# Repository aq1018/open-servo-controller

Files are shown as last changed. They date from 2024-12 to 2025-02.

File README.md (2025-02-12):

# open-servo-controller

An smart open servo controller board and firmware for common servos such as SG90 / MG90.

## Goals

Currently this project is under development. I'm working on this in my spare time and there is no guarantee that any of the goals will be achieved at all.

* More sophisticated control scheme via cascaded control loops instead of simple PID.
* Allow Position / Torque / Current feedback.
* I2C & UART communication.
* Clear and easy instructions to modify existing servos.
* Arduino plugin to control servo via I2C / UART.

## Status

* **Servo Dev Board** (`hardware/servo-dev-board`) - This is the board first developed to facility the development of the firmware. Currently, all major components except I2C & UART has been tested to be working correctly.
* **Firmware** (`firmware/open-servo-controller`) - The firmware is written in Rust. This is currently under active development.

All other folders are not ready yet.

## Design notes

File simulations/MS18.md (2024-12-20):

# Miuzei Micro Servo 9g MS18 ( SG90 Clone )

This is a tower-pro SG90 Clone.

## Motor Constants

### Motor Resistance - *R*

**5Ω**

This is measured by supplying 5V of power from a power bench, hold down the motor to prevent it from spinning to induce stalling, and recording the current draw. On average, the stall current at 5V is 1A.

### RPM

**6,000 RPM @ 5V**

This measured by matching the motor noise pitch against a reference pure sign wave pitch. It is determined to be at 600Hz at 5V. Since the motor has 3 winds / poles, and 2 brushes, it will make a sound 6 times per revolution. This gives us 600Hz/6 = 100Hz. Or 6,000 RPM.

### No Load Current - i<sub>o</sub>

**135mA**

This measured by supplying a 5V power and let the motor spin freely. The resulting current measurement is averaged.

### Motor Speed Constant - K<sub>v</sub>

Formula: Kv = RPM/(v − i<sub>o</sub>R) = (6,000 * PI / 30) / (5 - 0.135 * 5) = **145.276 Rad/s/V**

### Motor Torque Constant - K<sub>t</sub>

Formula: 1/Kv ( in standard metrics ) = 6.883 * 10^-3 N*m/A

### Motor Constant - K<sub>m</sub>

Formula: K<sub>m</sub> = K<sub>t</sub>/sqrt(R) = 3.078 * 10^-3 N*m/sqrt(W)

### Stall Current

Formula: I = V/R = 5/5 = 1A

## Stall Torque

Formula: T<sub>s</sub> = I<sub>s</sub> * K<sub>t</sub> = 6.883 * 10^-3 N*m

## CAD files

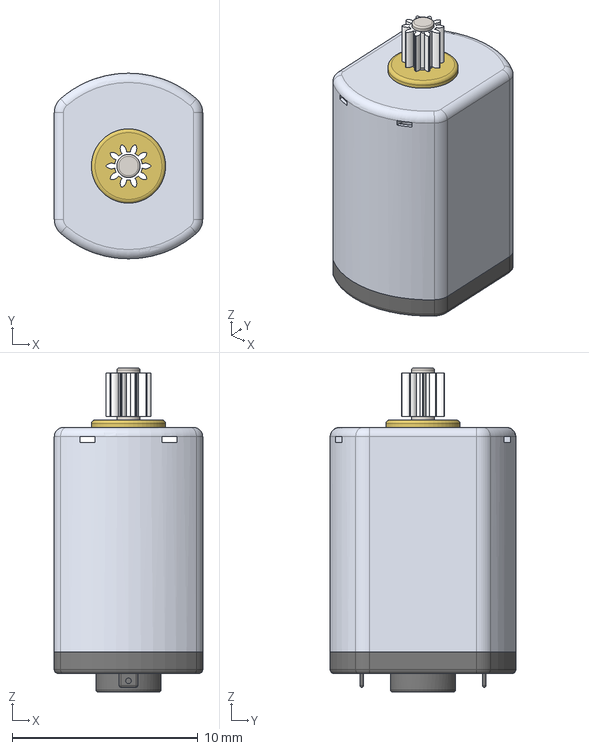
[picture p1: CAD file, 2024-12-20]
hardware/common/3DModels/sg90_motor.stp
8.00 x 10.0 x 17.4 mm
microBrushedMotor x 4
Gear5

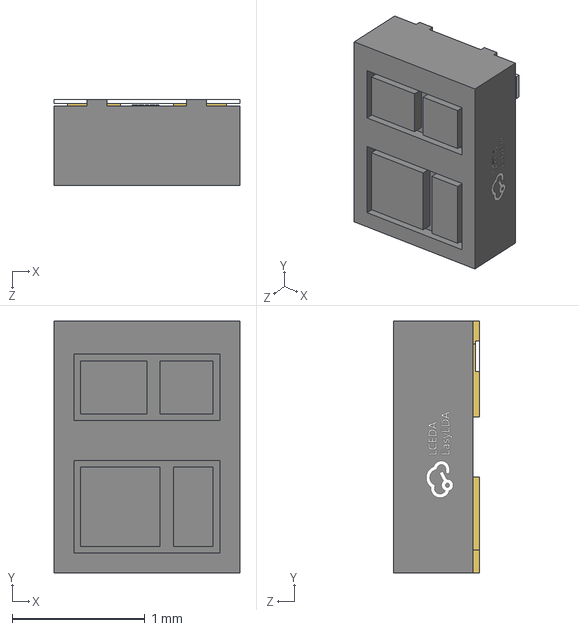
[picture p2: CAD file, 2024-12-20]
hardware/common/3DModels/OPTO-SMD-4_ITR1204SR10A.step
1.40 x 1.90 x 0.651 mm

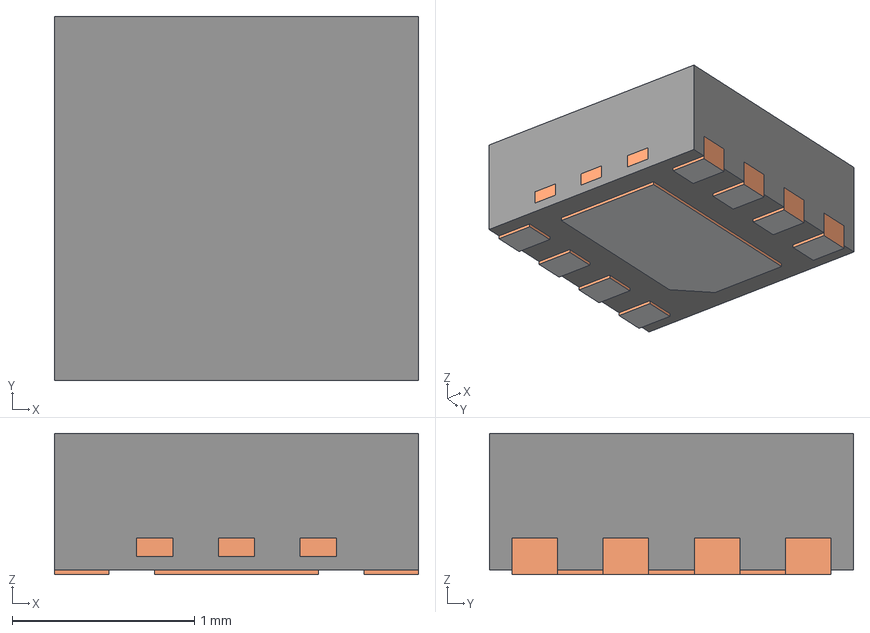
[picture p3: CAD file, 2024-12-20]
hardware/common/3DModels/DSG0008A.stp
2.00 x 2.00 x 0.775 mm
BODY-SON
FRAME-DSG0008A
PIN1-ID

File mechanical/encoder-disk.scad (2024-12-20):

include <./lib/gears.scad>

difference() {
    $fn = 128;
    cylinder(3, 10, 10);

    translate([0,0,0.5]) {
        spur_gear(0.23, 10, 3, 0);
    }
}

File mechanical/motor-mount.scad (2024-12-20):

module arc(start, end, angle, dir = "cw") {
  // find the distance of start and end vectors.
  x = end.x - start.x; // 3
  y = end.y - start.y; // 4
  d = sqrt(x * x + y * y); // 5
  rotation = atan2(y, x);

  opposite = d / 2;
  hypotenuse = opposite / sin(angle / 2);
  adjacent = cos(angle / 2) * hypotenuse;

  echo(hypotenuse, opposite, adjacent, rotation);

  translate([x/2 + start.x, y/2 + start.y, 0])
  rotate(dir == "cw" ? rotation : -rotation, [0, 0, 1])
  translate([0, - adjacent, 0])
  difference() {
    circle(hypotenuse, $fn=100);
    translate([0, adjacent - hypotenuse, 0]) 
      square(hypotenuse*2, true);
  }


    // translate([-opposite*sin(rotation), -opposite*cos(rotation), 0])
    // rotate(-rotation, [0, 0, 1])
    //   square(hypotenuse*2, true);
}

module outline(r, delta, chamfer) {
  difference() {
    offset(r=r, delta=delta, chamfer=chamfer) children();
    children();
  }
}

module motor_mount(length=6, width=8, diameter=10, thickness=2) {

    // intersection() {
      square([length, width], true);
      circle(d=diameter);
    // }

}

motor_mount();

// arc([3, 2], [3, -2], 80);

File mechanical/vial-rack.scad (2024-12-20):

function offset(edge_spacing, spacing, hole_diameter, col, row) = [
  edge_spacing.x + hole_diameter / 2 + (hole_diameter + spacing.x) * col,
  edge_spacing.y + hole_diameter / 2 + (hole_diameter + spacing.y) * row,
];

module vial_rack_leg(leg_size, leg_thickness) {
  difference() {
    cube([leg_size.x, leg_size.y, leg_size.z]);
    translate([leg_thickness, leg_thickness, -1]) cube([leg_size.x - leg_thickness + 1, leg_size.y - leg_thickness + 1, leg_size.z + 2]);
  }
}

module vial_rack(
  hole_diameter = 15,
  thickness = 8,
  grid = [10, 5],
  spacing = [10, 10],
  edge_spacing = [15, 15],
  leg_size = [15, 15, 35],
  leg_thickness = 5,
) {
  length = (hole_diameter + spacing.x) * grid.x - spacing.x + edge_spacing.x * 2;
  width = (hole_diameter + spacing.y) * grid.y - spacing.y + edge_spacing.y * 2;

  translate([-length/2, -width/2]) {
    union() {
      // rack top
      difference() {
        cube([length, width, thickness]);

        union() {
          for (x = [0:grid.x - 1]) {
            for (y = [0:grid.y - 1]) {
              pos = offset(edge_spacing, spacing, hole_diameter, x, y);
              translate([pos.x, pos.y, -1]) {
                cylinder(h=thickness + 2, d=hole_diameter);
              }
            }
          }
        }
      }

      // rack leg lower left
      translate([0, 0, thickness]) {
        rotate(0) {
          vial_rack_leg(leg_size, leg_thickness);
        }
      }

      // rack leg lower right
      translate([length, 0, thickness]) {
        rotate(90) {
          vial_rack_leg(leg_size, leg_thickness);
        }
      }

      // rack leg upper right
      translate([length, width, thickness]) {
        rotate(180) {
          vial_rack_leg(leg_size, leg_thickness);
        }
      }

      // rack leg upper left
      translate([0, width, thickness]) {
        rotate(270) {
          vial_rack_leg(leg_size, leg_thickness);
        }
      }
    }
  }
}

vial_rack();

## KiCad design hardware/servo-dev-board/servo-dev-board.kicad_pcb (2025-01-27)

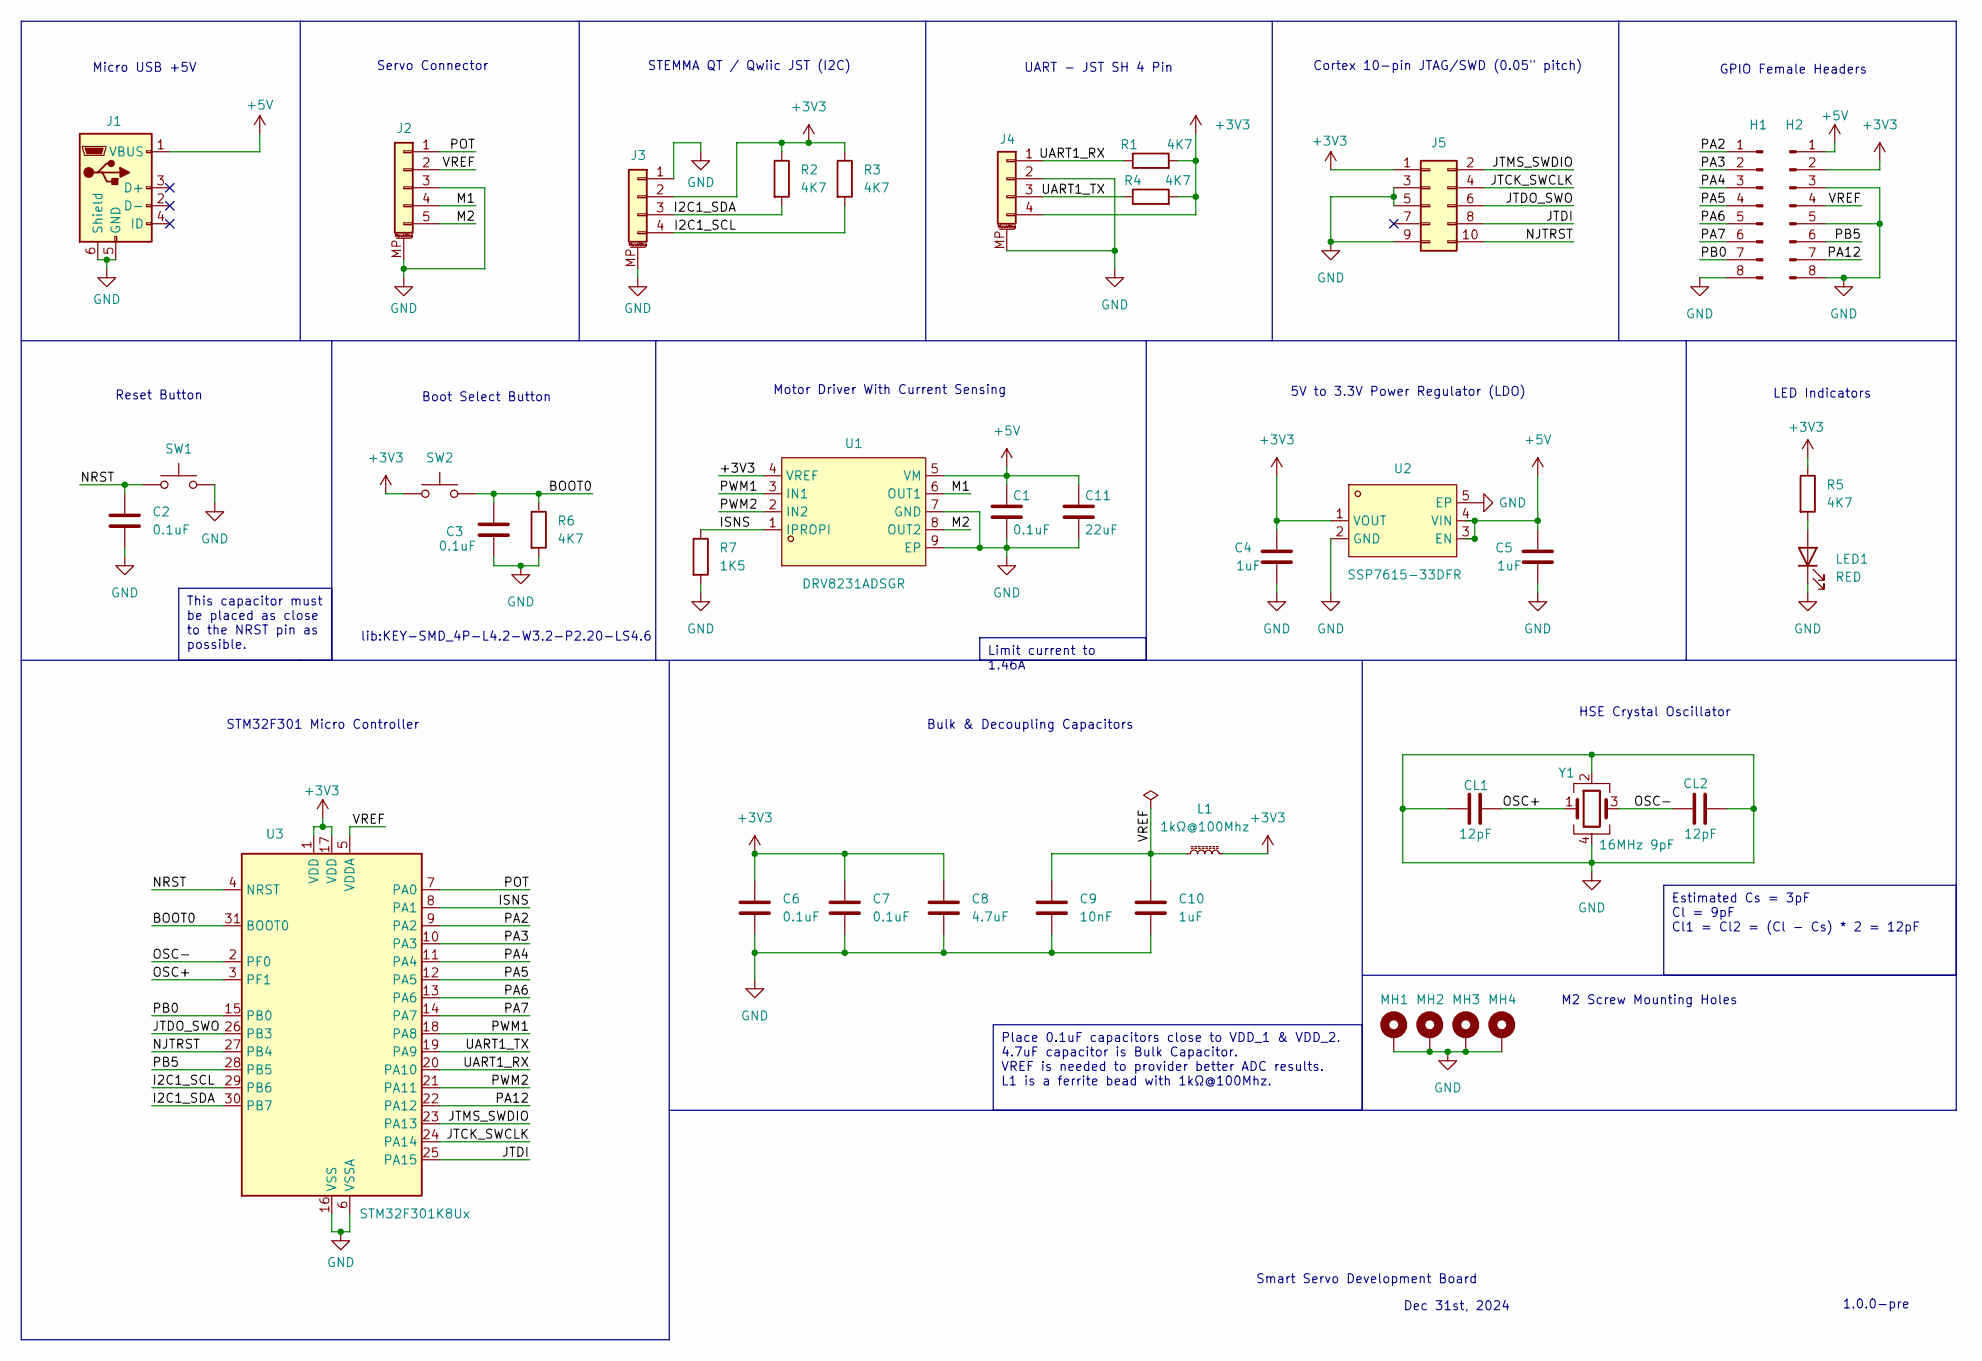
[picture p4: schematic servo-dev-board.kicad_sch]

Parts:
C1, C2, C3, C6, C7: 0.1uF; C_0402_1005Metric; LCSC C1525
C4, C5, C10: 1uF; C_0402_1005Metric; LCSC C52923
C8: 4.7uF; C_0603_1608Metric; LCSC C19666
C9: 10nF; C_0402_1005Metric; LCSC C15195
C11: 22uF; C_0603_1608Metric; LCSC C59461
CL1, CL2: 12pF; C_0402_1005Metric; LCSC C1547
H1, H2: Conn_01x08_Pin; PinHeader_1x08_P2.54mm_Vertical; LCSC C6332201
J1: USB_B_Micro; USB_Micro-B_Amphenol_10103594-0001LF_Horizontal; LCSC C428495
J2: Conn_01x05_MountingPin; JST_ZH_B5B-ZR-SM4-TF_1x05-1MP_P1.50mm_Vertical; LCSC C265440
J3, J4: Conn_01x04_MountingPin; JST_SH_BM04B-SRSS-TB_1x04-1MP_P1.00mm_Vertical; LCSC C160390
J5: Conn_02x05_Odd_Even; IDC-TH_10P-P1.27-X1270WV-2X05A-6TV01; LCSC C2962225
L1: 1kΩ@100Mhz; L_0402_1005Metric; LCSC C76883
LED1: RED; LED_0603_1608Metric; LCSC C2286
MH1, MH2, MH3, MH4: MountingHole_Pad_MP; MountingHole_2.2mm_M2_Pad_Via
R1, R2, R3, R4, R5, R6: 4K7; R_0402_1005Metric; LCSC C25792
R7: 1K5; R_0402_1005Metric; LCSC C25867
SW1, SW2: SW_Push; SW_SPST_PTS810; LCSC C221895
U1: DRV8231ADSGR; WSON-8-1EP_2x2mm_P0.5mm_EP0.9x1.6mm; LCSC Part C5139865
U2: SSP7615-33DFR; UDFN-4-1EP_1x1mm_P0.65mm_EP0.48x0.48mm; LCSC Part C3011523
U3: STM32F301K8Ux; QFN-32-1EP_5x5mm_P0.5mm_EP3.45x3.45mm; LCSC C111684
Y1: 16MHz 9pF; Crystal_SMD_3225-4Pin_3.2x2.5mm; LCSC C13738

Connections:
+3V3: C4.2, C6.2, C7.2, C8.2, H2.2, J3.2, J4.4, J5.1, L1.2, R1.2, R2.1, R3.1, R4.2, R5.1, SW2.1, U1.4 (VREF), U2.1 (VOUT), U3.1 (VDD), U3.17 (VDD)
+5V: C1.2, C5.2, C11.2, H2.1, J1.1 (VBUS), U1.5 (VM), U2.3 (EN), U2.4 (VIN)
/BOOT0: C3.1, R6.1, SW2.2, U3.31 (BOOT0)
/I2C1_SCL: J3.4, R3.2, U3.29 (PB6)
/I2C1_SDA: J3.3, R2.2, U3.30 (PB7)
/ISNS: R7.1, U1.1 (IPROPI), U3.8 (PA1)
/JTCK_SWCLK: J5.4, U3.24 (PA14)
/JTDI: J5.8, U3.25 (PA15)
/JTDO_SWO: J5.6, U3.26 (PB3)
/JTMS_SWDIO: J5.2, U3.23 (PA13)
/M1: J2.4, U1.6 (OUT1)
/M2: J2.5, U1.8 (OUT2)
/NJTRST: J5.10, U3.27 (PB4)
/NRST: C2.2, SW1.1, U3.4 (NRST)
/OSC+: CL1.1, U3.3 (PF1), Y1.1
/OSC-: CL2.2, U3.2 (PF0), Y1.3
/PA2: H1.1, U3.9 (PA2)
/PA3: H1.2, U3.10 (PA3)
/PA4: H1.3, U3.11 (PA4)
/PA5: H1.4, U3.12 (PA5)
/PA6: H1.5, U3.13 (PA6)
/PA7: H1.6, U3.14 (PA7)
/PA12: H2.7, U3.22 (PA12)
/PB0: H1.7, U3.15 (PB0)
/PB5: H2.6, U3.28 (PB5)
/POT: J2.1, U3.7 (PA0)
/PWM1: U1.3 (IN1), U3.18 (PA8)
/PWM2: U1.2 (IN2), U3.21 (PA11)
/UART1_RX: J4.1, R1.1, U3.20 (PA10)
/UART1_TX: J4.3, R4.1, U3.19 (PA9)
/VREF: C9.2, C10.2, H2.4, J2.2, L1.1, U3.5 (VDDA)
GND: C1.1, C2.1, C3.2, C4.1, C5.1, C6.1, C7.1, C8.1, C9.1, C10.1, C11.1, CL1.2, CL2.1, H1.8, H2.3, H2.5, H2.8, J1.5 (GND), J1.6 (Shield), J2.3, J2.MP (MountPin), J3.1, J3.MP (MountPin), J4.2, J4.MP (MountPin), J5.3, J5.5, J5.9, LED1.1 (K), MH1.1 (MP), MH2.1 (MP), MH3.1 (MP), MH4.1 (MP), R6.2, R7.2, SW1.2, U1.7 (GND), U1.9 (EP), U2.2 (GND), U2.5 (EP), U3.6 (VSSA), U3.16 (VSS), U3.32 (VSS), U3.33 (VSS), Y1.2, Y1.4
unnamed: LED1.2 (A), R5.2

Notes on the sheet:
This capacitor must be placed as close to the NRST pin as possible.
Place 0.1uF capacitors close to VDD_1 & VDD_2. 4.7uF capacitor is Bulk Capacitor. VREF is needed to provider better ADC results. L1 is a ferrite bead with 1kΩ@100Mhz.
Limit current to 1.46A
Estimated Cs = 3pF Cl = 9pF Cl1 = Cl2 = (Cl - Cs) * 2 = 12pF
Cortex 10-pin JTAG/SWD (0.05" pitch)
Dec 31st, 2024
Reset Button
Smart Servo Development Board
STM32F301 Micro Controller
Boot Select Button
Servo Connector
Bulk & Decoupling Capacitors
GPIO Female Headers
1.0.0-pre
5V to 3.3V Power Regulator (LDO)
LED Indicators
Micro USB +5V
M2 Screw Mounting Holes
UART - JST SH 4 Pin
STEMMA QT / Qwiic JST (I2C)
HSE Crystal Oscillator
lib:KEY-SMD_4P-L4.2-W3.2-P2.20-LS4.6
Motor Driver With Current Sensing

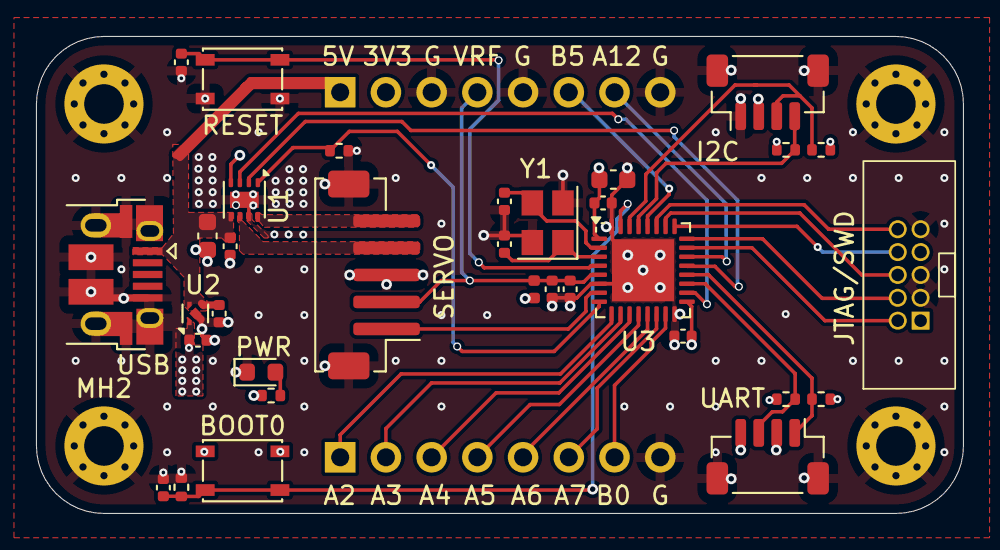
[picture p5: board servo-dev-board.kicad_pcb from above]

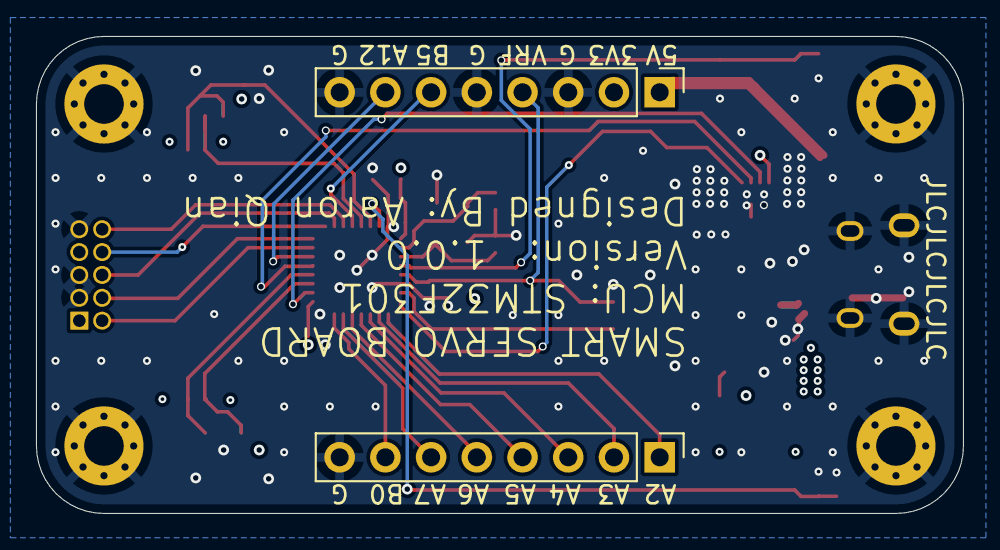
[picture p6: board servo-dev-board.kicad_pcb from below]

Board: 4 copper layers, 51.5 x 26.5 mm, 39 parts (2 on the bottom side), 33 nets.

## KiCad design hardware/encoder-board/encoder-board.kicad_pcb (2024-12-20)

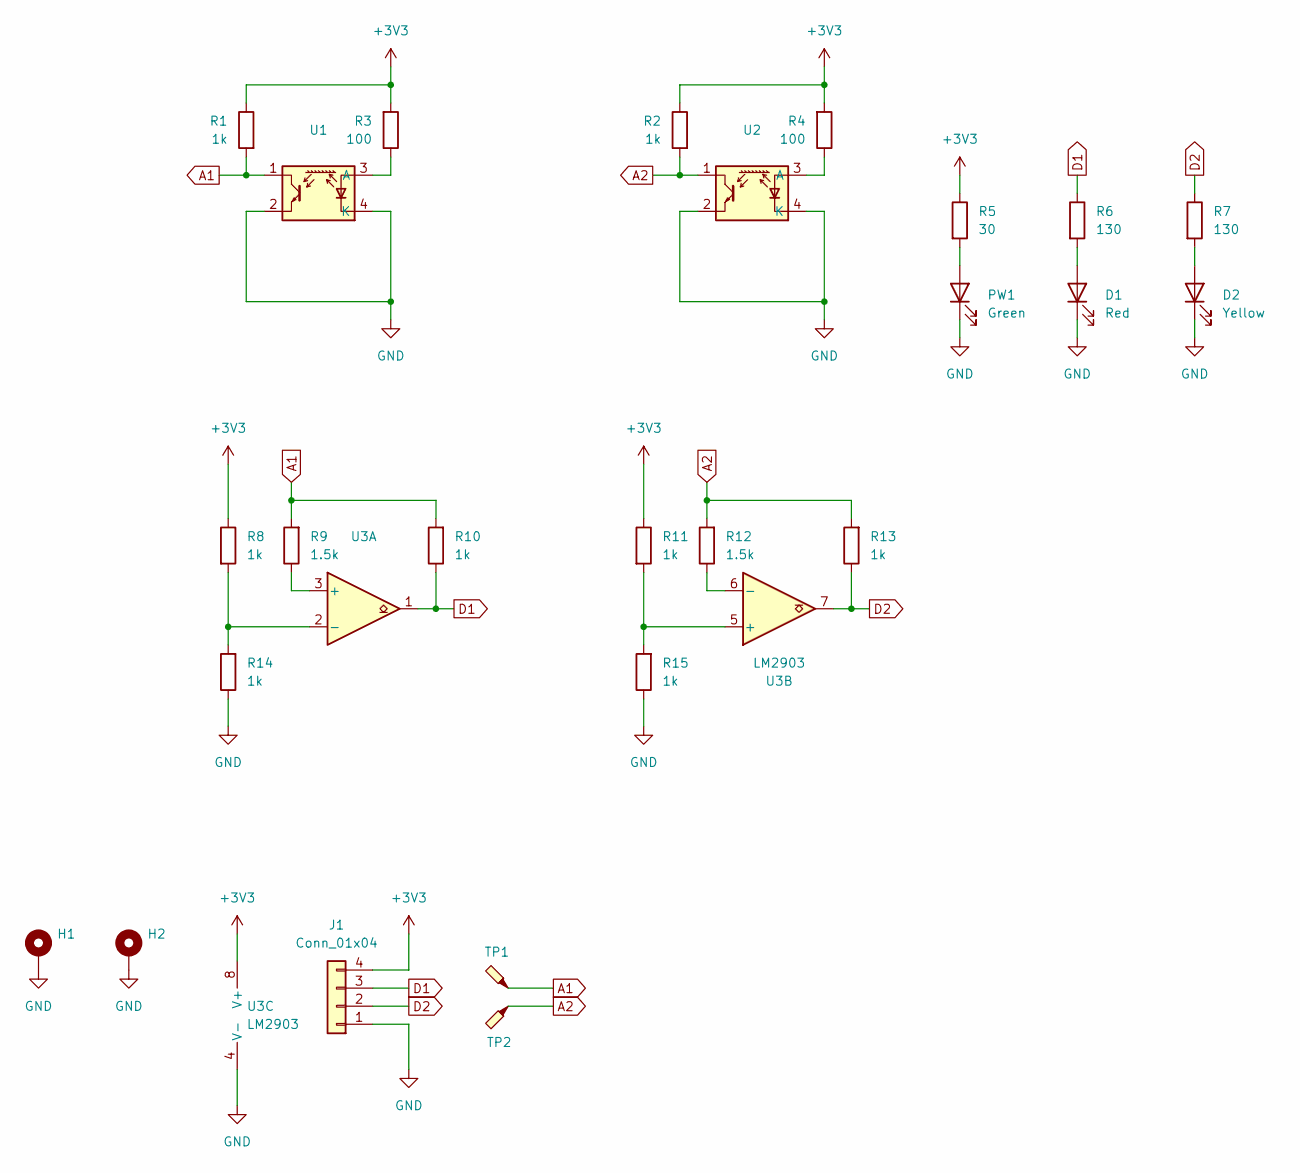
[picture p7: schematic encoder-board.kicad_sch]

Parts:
D1: Red; LED_0603_1608Metric; LCSC C497918
D2: Yellow; LED_0603_1608Metric; LCSC C497929
H1, H2: MountingHole_Pad; MountingHole_2.2mm_M2_ISO7380_Pad
J1: Conn_01x04; PinHeader_1x04_P2.54mm_Vertical_SMD_Pin1Right; LCSC C780062
PW1: Green; LED_0603_1608Metric; LCSC C497927
R1, R2, R8, R10, R11, R13, R14, R15: 1k; R_0603_1608Metric; LCSC C22548
R3, R4: 100; R_0603_1608Metric; LCSC C125923
R5: 30; R_0603_1608Metric; LCSC C128060
R6, R7: 130; R_0603_1608Metric; LCSC C2933138
R9, R12: 1.5k; R_0603_1608Metric; LCSC C114668
TP1, TP2: TestPoint_Pad_D1.0mm
U1, U2: ITR1204SR10A_TR(BY); OPTO-SMD-4_ITR1204SR10A; LCSC C475373
U3: LM2903; SOIC-8_3.9x4.9mm_P1.27mm; LCSC C98194

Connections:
+3V3: J1.4, R1.1, R2.1, R3.2, R4.2, R5.1, R8.1, R11.1, U3.8 (V+)
A1: R1.2, R9.2, R10.2, TP1.1, U1.1
A2: R2.2, R12.2, R13.2, TP2.1, U2.1
D1: J1.3, R6.1, R10.1, U3.1
D2: J1.2, R7.1, R13.1, U3.7
GND: D1.1 (K), D2.1 (K), H1.1, H2.1, J1.1, PW1.1 (K), R14.1, R15.1, U1.2, U1.4 (K), U2.2, U2.4 (K), U3.4 (V-)
unnamed: D1.2 (A), R6.2
unnamed: D2.2 (A), R7.2
unnamed: PW1.2 (A), R5.2
unnamed: R3.1, U1.3 (A)
unnamed: R4.1, U2.3 (A)
unnamed: R9.1, U3.3 (+)
unnamed: R8.2, R14.2, U3.2 (-)
unnamed: R11.2, R15.2, U3.5 (+)
unnamed: R12.1, U3.6 (-)

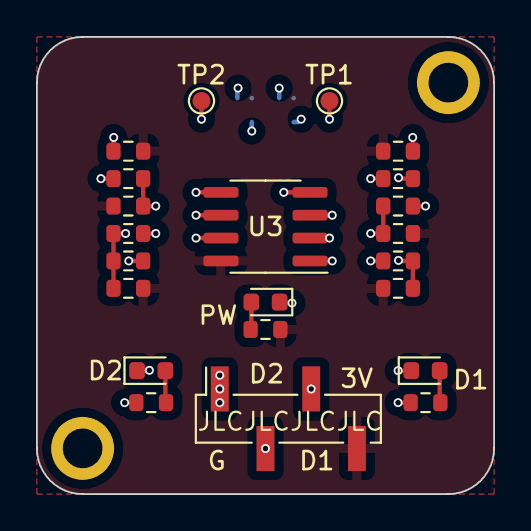
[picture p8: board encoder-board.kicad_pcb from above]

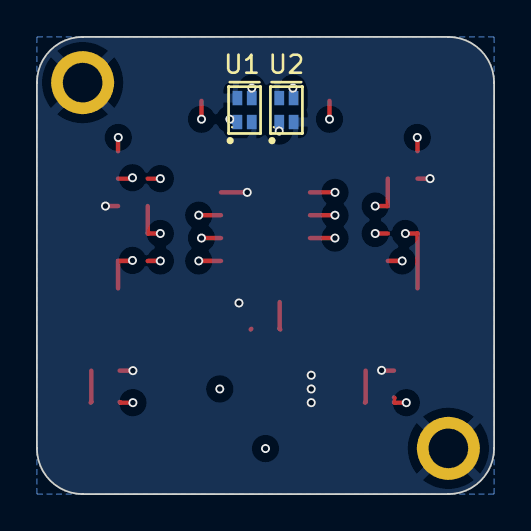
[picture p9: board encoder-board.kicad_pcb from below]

Board: 4 copper layers, 25.4 x 25.4 mm, 26 parts (2 on the bottom side), 15 nets.

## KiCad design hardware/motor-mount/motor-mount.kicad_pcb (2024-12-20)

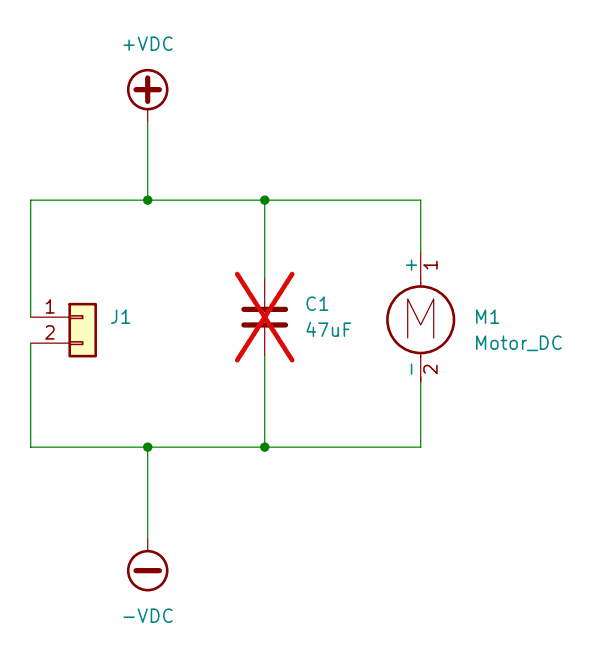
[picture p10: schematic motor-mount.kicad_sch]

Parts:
C1: 47uF; C_1206_3216Metric; not fitted
J1: PinHeader_1x02_P2.54mm_Vertical
M1: Motor_DC; SG90_Motor

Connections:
+VDC: C1.1, J1.1, M1.1 (+)
-VDC: C1.2, J1.2, M1.2 (-)

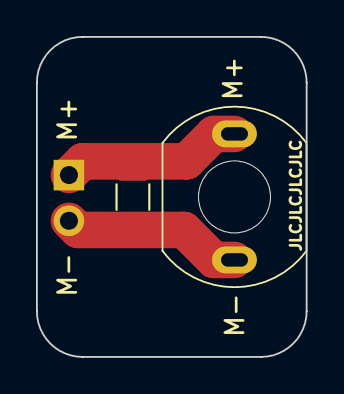
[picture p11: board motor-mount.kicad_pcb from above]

Board: 2 copper layers, 15.0 x 17.8 mm, 3 parts (1 on the bottom side), 2 nets.

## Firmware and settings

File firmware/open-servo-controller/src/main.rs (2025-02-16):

#![no_main]
#![no_std]

use defmt_rtt as _;
use panic_probe as _;

use core::cell::RefCell;
use cortex_m::{
    asm,
    interrupt::{free, Mutex},
};
use cortex_m_rt::entry;
use pid::Pid;
use stm32f3::stm32f301 as pac;

use pac::interrupt;

#[derive(Copy, Clone, defmt::Format)]
struct SystemState {
    // Desired Servo Position
    pub setpoint: u16,

    // Current Servo Position
    pub position: u16,

    // PWM Duty Cycle
    pub pwm_duty: i32,

    // Current in mA
    pub current: f32,

    // VDDA Voltage
    pub vdda: f32,

    // Chip Temperature in Celsius
    pub temperature: f32,
}

impl SystemState {
    fn new() -> Self {
        SystemState {
            setpoint: 0,
            position: 0,
            pwm_duty: 0,
            current: 0.0,
            vdda: 0.0,
            temperature: 0.0,
        }
    }
}

const VREFINT_CAL_ADDR: u32 = 0x1FFFF7BA;
const TS_CAL1_ADDR: u32 = 0x1FFFF7B8;
const TS_CAL2_ADDR: u32 = 0x1FFFF7C2;

// RCC parameters
// const RCC_HSE_CLOCK_HZ: u32 = 16_000_000;
const RCC_SYSCLK_HZ: u32 = 72_000_000;

// Current sense parameters
const ISENSE_AIPROPI: f32 = 1500.0; // uA/A
const ISENSE_RESISTOR_OHM: f32 = 2200.0; // Ohm
const ISENSE_FACTOR: f32 = ISENSE_AIPROPI / ISENSE_RESISTOR_OHM; // uA / V

// PWM parameters
const PWM_FREQUENCY: u32 = 20_000;
const PWM_MAX_DUTY: u16 = ((RCC_SYSCLK_HZ / PWM_FREQUENCY / 2) - 1) as u16;
const PWM_REVERSE: bool = false;

// PID controller parameters
const PID_KP: f32 = 40.0;
const PID_KI: f32 = 0.0;
const PID_KD: f32 = 0.0;
const PID_KP_MAX: f32 = PWM_MAX_DUTY as f32;
const PID_KI_MAX: f32 = PWM_MAX_DUTY as f32 * 0.8;
const PID_KD_MAX: f32 = PWM_MAX_DUTY as f32 * 0.8;
const PID_OUTPUT_MAX: f32 = PWM_MAX_DUTY as f32;

static ADC_DATA: Mutex<RefCell<Option<&[u16; 5]>>> = Mutex::new(RefCell::new(Option::None));
static PID_CONTROLLER: Mutex<RefCell<Option<Pid<f32>>>> = Mutex::new(RefCell::new(Option::None));
static SYSTEM_STATE: Mutex<RefCell<Option<SystemState>>> = Mutex::new(RefCell::new(Option::None));

#[entry]
fn main() -> ! {
    let p = pac::Peripherals::take().unwrap();

    init_rcc(&p);
    init_tim1_pwm(&p);
    init_tim2_counter(&p);
    init_led(&p);
    init_dma(&p);
    init_adc(&p);

    // intialize PID controller
    let mut pid: Pid<f32> = Pid::new(0.0, PID_OUTPUT_MAX);
    pid.p(PID_KP, PID_KP_MAX);
    pid.i(PID_KI, PID_KI_MAX);
    pid.d(PID_KD, PID_KD_MAX);
    free(|cs| PID_CONTROLLER.borrow(cs).replace(Some(pid)));

    // initialize system state
    let system_state = SystemState::new();
    free(|cs| SYSTEM_STATE.borrow(cs).replace(Some(system_state)));

    // enable interrupts
    unsafe {
        pac::NVIC::unmask(pac::Interrupt::TIM2);
        pac::NVIC::unmask(pac::Interrupt::DMA1_CH1);
    }

    defmt::info!("Initialized");

    // start ADC conversion
    p.ADC1.cr.modify(|_, w| w.adstart().start_conversion());

    loop {}
}

// interrupt handler for TIM2
#[interrupt]
fn TIM2() {
    defmt::info!("TIM2 interrupt");

    // toggle PA3
    unsafe {
        (*pac::GPIOA::ptr())
            .odr
            .modify(|r, w| w.odr3().bit(!r.odr3().bit()));
    }

    // clone system state to local variable
    let system_state = free(|cs| SYSTEM_STATE.borrow(cs).borrow().unwrap());
    defmt::info!("{}", system_state);

    // clear interrupt flag
    unsafe {
        (*pac::TIM2::ptr()).sr.modify(|_, w| w.uif().clear());
    }
}

#[interrupt]
fn DMA1_CH1() {
    let dma1 = unsafe { &(*pac::DMA1::ptr()) };
    let [is_complete, is_error] = cortex_m::interrupt::free(|_| {
        [
            dma1.isr.read().tcif1().is_complete(),
            dma1.isr.read().teif1().is_error(),
        ]
    });

    // check interrupt flag for transfer complete
    if !is_complete {
        defmt::info!("Transfer complete interrupt flag not set");
        return;
    }

    // check interrupt flag for transfer error
    if is_error {
        defmt::error!("Transfer error interrupt flag set");
        return;
    }

    // clone ADC_DATA to local variable
    let [vref, pot, isns, mut setpoint, temp] =
        free(|cs| ADC_DATA.borrow(cs).borrow().unwrap().clone());

    // hardcode for now
    setpoint = 2048;

    // calculate pwm duty cycle using PID controller
    let pid_output = free(|cs| {
        let mut pid_option = PID_CONTROLLER.borrow(cs).borrow_mut();
        let pid = pid_option.as_mut().unwrap();
        pid.setpoint(setpoint).next_control_output(pot as f32)
    });
    let mut duty: i32 = pid_output.output as i32;
    if PWM_REVERSE {
        duty = duty * -1;
    }

    // set PWM duty cycle
    let tim1 = unsafe { &(*pac::TIM1::ptr()) };
    if duty > 0 {
        let duty: u16 = duty as u16;

        tim1.ccr1().write(|w| w.ccr().bits(duty));
        tim1.ccr4().write(|w| w.ccr().bits(0));
    } else {
        let duty: u16 = (duty * -1) as u16;

        tim1.ccr1().write(|w| w.ccr().bits(0));
        tim1.ccr4().write(|w| w.ccr().bits(duty));
    }

    // convert ADC values to physical values
    let vdda = convert_vdda(vref);
    let temp = convert_temperature(temp, vdda);
    let current = convert_current(isns, vdda);

    // update system state
    free(|cs| {
        let mut system_state_options = SYSTEM_STATE.borrow(cs).borrow_mut();
        let system_state = system_state_options.as_mut().unwrap();

        system_state.setpoint = setpoint;
        system_state.position = pot;
        system_state.pwm_duty = duty;
        system_state.vdda = vdda;
        system_state.current = current;
        system_state.temperature = temp;
    });

    // clear interrupt flag
    unsafe {
        (*pac::DMA1::ptr()).ifcr.write(|w| w.cgif1().set_bit());
    }
}

fn convert_temperature(adc_value: u16, vdda_value: f32) -> f32 {
    let ts_cal1: u16 = unsafe { core::ptr::read(TS_CAL1_ADDR as *const u16) };
    let ts_cal2: u16 = unsafe { core::ptr::read(TS_CAL2_ADDR as *const u16) };
    let ts_cal1_temp: f32 = 30.0;
    let ts_cal2_temp: f32 = 110.0;
    let ts_cal1_voltage: f32 = 3.3 * ts_cal1 as f32 / 4095.0;
    let ts_cal2_voltage: f32 = 3.3 * ts_cal2 as f32 / 4095.0;
    let ts_slope: f32 = (ts_cal2_temp - ts_cal1_temp) / (ts_cal2_voltage - ts_cal1_voltage);
    let ts_offset: f32 = ts_cal1_temp - ts_slope * ts_cal1_voltage;
    let temp_voltage = vdda_value * adc_value as f32 / 4095.0;
    let temp = ts_slope * temp_voltage + ts_offset;
    return temp;
}

fn convert_vdda(adc_value: u16) -> f32 {
    let vrefint_cal: u16 = unsafe { core::ptr::read(VREFINT_CAL_ADDR as *const u16) };
    let vdda = 3.3 * vrefint_cal as f32 / adc_value as f32;
    return vdda;
}

fn convert_voltage(adc_value: u16, vdda_value: f32) -> f32 {
    vdda_value * adc_value as f32 / PWM_MAX_DUTY as f32
}

fn convert_current(adc_value: u16, vdda_value: f32) -> f32 {
    let isense_voltage = convert_voltage(adc_value, vdda_value);
    let current = isense_voltage * ISENSE_FACTOR / 1000.0; // convert uA to mA
    return current;
}

fn init_dma(p: &pac::Peripherals) {
    // enable DMA1 Channel 1
    p.DMA1.ch1.cr.modify(|_, w| {
        w.pl()
            .low() // low priority
            .circ()
            .enabled() // enable circular mode
            .dir()
            .from_peripheral() // read from peripheral
            .msize()
            .bits16() // 16 bit memory size
            .psize()
            .bits16() // 16 bit peripheral size
            .tcie()
            .enabled() // enable transfer complete interrupt
            .teie()
            .enabled() // enable transfer error interrupt
            .mem2mem()
            .disabled() // memory to memory mode disabled
            .minc()
            .enabled() // increment memory address
            .pinc()
            .disabled() // do not increment peripheral address
    });

    p.DMA1
        .ch1
        .par
        .write(|w| unsafe { w.bits(p.ADC1.dr.as_ptr() as u32) }); // set peripheral address to ADC1_DR

    let adc_data = cortex_m::singleton!(: [u16; 5] = [0; 5]).unwrap();
    p.DMA1
        .ch1
        .mar
        .write(|w| unsafe { w.bits(adc_data.as_ptr() as u32) }); // set memory address to ADC_DATA

    free(|cs| ADC_DATA.borrow(cs).replace(Some(adc_data)));

    // set number of data to transfer to 5 because we are converting 5 channels
    p.DMA1.ch1.ndtr.write(|w| w.ndt().bits(5));

    // enable DMA1 Channel 1
    p.DMA1.ch1.cr.modify(|_, w| w.en().enabled());
}

fn init_adc(p: &pac::Peripherals) {
    let adc1 = &p.ADC1;

    /*
     * Configure ADC
     */
    p.ADC1_2.ccr.modify(|_, w| {
        w.ckmode()
            .sync_div1() // use synchronous clock mode
            .tsen()
            .enabled() // enable temperature sensor
            .vrefen()
            .enabled() // enable VREFINT
    });

    adc1.cfgr.modify(|_, w| {
        w.res()
            .bits12() // set ADC to 12 bit resolution
            .align()
            .right() // set ADC to right aligned
            .cont()
            .single() // set ADC to single conversion mode
            .discen()
            .disabled() // set ADC to disable discontinuous mode
            .dmacfg()
            .circular() // set ADC to circular DMA mode
            .dmaen()
            .enabled() // enable DMA
            .ovrmod()
            .preserve() // set ADC to preserve overrun
            .exten()
            .rising_edge() // set ADC to rising edge trigger
            .extsel()
            .tim1_trgo2() // set ADC to TIM1_TRGO2
    });

    /*
     * ADC calibration
     */
    // enable internal voltage regulator
    adc1.cr.modify(|_, w| w.advregen().intermediate());
    adc1.cr.modify(|_, w| w.advregen().enabled());
    // we need to wait 10 us for the voltage regulator to stabilize
    // we are running at 72 MHz, so 1 us = 72 cycles
    asm::delay(10 * 72);

    // run calibration
    adc1.cr
        .modify(|_, w| w.adcaldif().single_ended().adcal().calibration());
    while adc1.cr.read().adcal().is_calibration() {}

    // disable the internal voltage regulator, the internal analog calibration is kept
    adc1.cr.modify(|_, w| w.advregen().intermediate());
    adc1.cr.modify(|_, w| w.advregen().disabled());

    // ADEN bit cannot be set during ADCAL=1 and 4 ADC clock cycle after the ADCAL bit is
    // cleared by hardware
    // ADC clock cycle is set to be 72 MHz / 1 = 72 MHz
    asm::delay(4);

    /*
     * Configure ADC Channels
     */
    // configure PA0, PA1, PA2 as analog input
    let gpioa = &p.GPIOA;
    gpioa
        .moder
        .modify(|_, w| w.moder0().analog().moder1().analog().moder2().analog());
    gpioa.pupdr.modify(|_, w| {
        w.pupdr0()
            .floating()
            .pupdr1()
            .floating()
            .pupdr2()
            .floating()
    });

    // configure channels for conversion
    adc1.sqr1.modify(|_, w| unsafe {
        w.l()
            .bits(4) // set number of conversions to 5, this register counts from 0
            .sq1()
            .bits(18) // set vrefint ( ch 18 ) as first conversion
            .sq2()
            .bits(1) // set PA0 ( ch 1 )  as second conversion
            .sq3()
            .bits(2) // set PA1 ( ch 2 )  as third conversion
            .sq4()
            .bits(3) // set PA2 ( ch 3 ) as fourth conversion
    });

    adc1.sqr2.modify(|_, w| unsafe {
        w.sq5().bits(16) // set tempature sensor ( ch 16 ) as first conversion
    });

    // set sample time for channels
    adc1.smpr1.modify(|_, w| {
        w.smp1()
            .cycles181_5() // PA0
            .smp2()
            .cycles181_5() // PA1
            .smp3()
            .cycles181_5() // PA2
    });

    adc1.smpr2.modify(|_, w| {
        w.smp16()
            .cycles181_5() // VREFINT
            .smp18()
            .cycles181_5() // Temperature sensor
    });

    /*
     * ENABLE ADC
     */
    adc1.cr.modify(|_, w| w.aden().enabled());
    while adc1.isr.read().adrdy().is_not_ready() {}
}

fn init_led(p: &pac::Peripherals) {
    let gpioa = &p.GPIOA;

    // configure PA3 as output
    gpioa.moder.modify(|_, w| w.moder3().output());

    // configure PA3 as push-pull
    gpioa.otyper.modify(|_, w| w.ot3().push_pull());

    // configure PA3 as high speed output
    gpioa.ospeedr.modify(|_, w| w.ospeedr3().high_speed());

    // configure PA3 as no pull-up, no pull-down
    gpioa.pupdr.modify(|_, w| w.pupdr3().floating());

    // set PA3 to low
    gpioa.odr.modify(|_, w| w.odr3().low());
}

fn init_tim2_counter(p: &pac::Peripherals) {
    let tim2 = &p.TIM2;

    // set prescaler to 72, so that the counter will increment every 1 us
    tim2.psc.write(|w| w.psc().bits(72));

    // set auto-reload register to 100_000, so that the counter will overflow every 0.1 second
    tim2.arr.write(|w| unsafe { w.arr().bits(100_000) });

    // generate an update event to load the prescaler value to the counter
    tim2.egr.write(|w| w.ug().update());

    // enable update interrupt
    tim2.dier.write(|w| w.uie().enabled());

    // enable TIM2
    tim2.cr1.write(|w| w.cen().enabled());
}

fn init_tim1_pwm(p: &pac::Peripherals) {
    let tim1 = &p.TIM1;

    // Enable auto-reload preload
    tim1.cr1.modify(|_, w| w.arpe().enabled());

    // set pwm mode to center aligned count up
    tim1.cr1.modify(|_, w| w.cms().center_aligned1().dir().up());

    // set PWM frequency to 10 kHz center aligned ( 20 KHz PWM frequency)
    tim1.arr.write(|w| w.arr().bits(3599)); // 72 MHz / 3600 = 20 kHz
    tim1.psc.write(|w| w.psc().bits(0)); // 72 MHz / 1 = 72 MHz

    // generate an update event to load the prescaler value to the counter
    tim1.egr.write(|w| w.ug().update());

    // enable main output enable
    tim1.bdtr.modify(|_, w| w.moe().enabled());

    // set trigger output to output compare 2 (OC3REF)
    // this is used to trigger ADC conversions
    tim1.cr2.modify(|_, w| unsafe {
        // See STM32F301 Reference Manual section 17.4.2.
        // MMS2 register is used to trigger ADC conversions
        w.mms2().bits(0b0110) // OC3REF
    });

    // enable TIM1
    tim1.cr1.modify(|_, w| w.cen().enabled());

    init_tim1_pwm_channels(p);
}

fn init_tim1_pwm_channels(p: &pac::Peripherals) {
    let gpioa = &p.GPIOA;
    let tim1 = &p.TIM1;

    // configure PA8 ( channel 1 ) as PWM output
    {
        // configure PA8 as alternate function
        gpioa.moder.modify(|_, w| w.moder8().alternate());

        // set PA8 alternate function map to TIM1_CH1 ( AF6 )
        gpioa.afrh.modify(|_, w| w.afrh8().af6());

        // configure PA8 as high speed output
        gpioa.ospeedr.modify(|_, w| w.ospeedr8().high_speed());

        // configure PA8 as push-pull
        gpioa.otyper.modify(|_, w| w.ot8().push_pull());

        // configure PA8 as pull down
        gpioa.pupdr.modify(|_, w| w.pupdr8().pull_down());

        // configure Channel 1 as PWM mode 1 and enable preload register
        tim1.ccmr1_output().modify(|_, w| {
            w.oc1pe()
                .enabled() // enable preload register for Channel 1
                .oc1m()
                .pwm_mode1() // PWM mode 1 for Channel 1
        });

        // set PWM duty cycle to 0
        tim1.ccr1().write(|w| w.ccr().bits(0));

        // enable PWM output
        tim1.ccer.write(|w| w.cc1e().set_bit());
    }

    // configure TIM channel 3 to PWM output
    {
        // configure TIM1 as output compare and enable preload register
        tim1.ccmr2_output().modify(|_, w| {
            w.oc3pe()
                .enabled() // enable preload register for Channel 3
                .oc3m()
                .pwm_mode1() // PWM mode 1 for Channel 3
        });

        // Set CCR to center of PWM period
        tim1.ccr3().modify(|_, w| w.ccr().bits(1));

        // enable PWM output
        tim1.ccer.modify(|_, w| w.cc3e().set_bit());
    }

    // configure PA11 ( channel 4 ) as PWM output
    {
        // configure PA11 as alternate function
        gpioa.moder.modify(|_, w| w.moder11().alternate());

        // set PA11 alternate function map to TIM1_CH4 ( AF11 )
        gpioa.afrh.modify(|_, w| w.afrh11().af11());

        // configure PA11 as high speed output
        gpioa.ospeedr.modify(|_, w| w.ospeedr11().high_speed());

        // configure PA11 as push-pull
        gpioa.otyper.modify(|_, w| w.ot11().push_pull());

        // configure PA11 as pull down
        gpioa.pupdr.modify(|_, w| w.pupdr11().pull_down());

        // configure TIM1 as PWM mode 1 and enable preload register
        tim1.ccmr2_output().modify(|_, w| {
            w.oc4pe()
                .enabled() // enable preload register for Channel 4
                .oc4m()
                .pwm_mode1() // PWM mode 1 for Channel 4
        });

        // set PWM duty cycle to 0
        tim1.ccr4().modify(|_, w| w.ccr().bits(0));

        // enable PWM output
        tim1.ccer.modify(|_, w| w.cc4e().set_bit());
    }
}

fn init_rcc(p: &pac::Peripherals) {
    let rcc = &p.RCC;
    let flash = &p.FLASH;

    // enable HSI clock
    rcc.cr.modify(|_, w| w.hsion().on());
    while rcc.cr.read().hsirdy().is_not_ready() {}

    // set HSI as system clock
    rcc.cfgr.modify(|_, w| w.sw().hsi());
    while !rcc.cfgr.read().sws().is_hsi() {}

    // enable HSE clock
    rcc.cr.modify(|_, w| w.hsebyp().not_bypassed().hseon().on());
    while rcc.cr.read().hserdy().is_not_ready() {}

    // configure PLL
    rcc.cfgr2.modify(|_, w| w.prediv().div2()); // HSE is 16 MHz, so divide by 2 to get 8 MHz
    rcc.cfgr.modify(|_, w| {
        w.pllsrc()
            .hse_div_prediv() // Use HSE as PLL source
            .pllmul()
            .mul9() // 8 MHz * 9 = 72 MHz
    });

    // enable PLL
    rcc.cr.modify(|_, w| w.pllon().on());
    while rcc.cr.read().pllrdy().is_not_ready() {}

    // set Flash latency to 2 wait states since we're running at 72 MHz
    flash.acr.write(|w| w.latency().ws2());

    // set AHB prescaler
    rcc.cfgr.modify(|_, w| {
        w.hpre()
            .div1() // AHB is 72 MHz
            .mcopre()
            .div1() // MCO is 72 MHz
            .ppre1()
            .div2() // APB1 is 36 MHz
            .ppre2()
            .div1() // APB2 is 72 MHz
    });

    // Wait for the new prescalers to kick in
    // "The clocks are divided with the new prescaler factor from
    //  1 to 16 AHB cycles after write"
    cortex_m::asm::delay(16);

    // switch to PLL
    rcc.cfgr.modify(|_, w| w.sw().pll());
    while !rcc.cfgr.read().sws().is_pll() {}

    // disable HSI
    rcc.cr.modify(|_, w| w.hsion().off());
    while rcc.cr.read().hsirdy().is_ready() {}

    // reset and enable Power Control
    // Enables access to the PWR_CR register
    // rcc.apb1enr.modify(|_, w| w.pwren().enabled());
    // rcc.apb1rstr.modify(|_, w| w.pwrrst().set_bit());
    // rcc.apb1rstr.modify(|_, w| w.pwrrst().clear_bit());

    // reset and enable System Configuration Controller
    // Enables access to the EXTI and COMP registers
    // rcc.apb2enr.modify(|_, w| w.syscfgen().enabled());
    // rcc.apb2rstr.modify(|_, w| w.syscfgrst().set_bit());
    // rcc.apb2rstr.modify(|_, w| w.syscfgrst().clear_bit());

    // enable FLITF clock
    // This provides read / write access to the Flash memory
    rcc.ahbenr.modify(|_, w| w.flitfen().enabled());

    // enable TIM1
    rcc.apb2enr.modify(|_, w| w.tim1en().enabled());
    rcc.apb2rstr.modify(|_, w| w.tim1rst().set_bit());
    rcc.apb2rstr.modify(|_, w| w.tim1rst().clear_bit());

    // enable TIM2
    rcc.apb1enr.modify(|_, w| w.tim2en().enabled());
    rcc.apb1rstr.modify(|_, w| w.tim2rst().set_bit());
    rcc.apb1rstr.modify(|_, w| w.tim2rst().clear_bit());

    // enable GPIOA, GPIOB, GPIOC
    rcc.ahbenr
        .modify(|_, w| w.iopaen().enabled().iopben().enabled().iopcen().enabled());

    // enable ADC1
    rcc.ahbenr.modify(|_, w| w.adc1en().enabled());
    rcc.ahbrstr.modify(|_, w| w.adc1rst().set_bit());
    rcc.ahbrstr.modify(|_, w| w.adc1rst().clear_bit());

    // enable DMA1
    rcc.ahbenr.modify(|_, w| w.dma1en().enabled());

    // delay for a bit to let the clocks settle
    cortex_m::asm::delay(65535);
}

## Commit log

2023-07-31 add measurement info for MS18 servo
2023-07-31 create initial kicad board
    [servo-test-board.kicad_pcb, servo-test-board.kicad_sch]
2023-07-31 add DRV8231ADSGR symbol footprint and 3d model
    [DSG0008A.stp]
2023-07-31 ignore kicad lock file
2023-07-31 configure board to use symbols lib
2023-07-31 add DRV8231A to schema
    [servo-test-board.kicad_sch]
2023-07-31 fix 3d model path of DRV8231ADSGR footprint
2023-07-31 add footprint to board
2023-07-31 update board and schema
    [servo-test-board.kicad_pcb, servo-test-board.kicad_sch]
2023-12-10 setup mono repo attempt 1
    [encoder-disk.scad, encoder-disk.stl, motor-mount.kicad_pcb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]
2023-12-10 reorganize monorepo
    [encoder-disk.stl]
2024-12-10 Add Servo Dev Board
    [servo-dev-board.kicad_pcb, servo-dev-board.kicad_sch]
2024-12-17 design pcb
    [servo-dev-board.kicad_pcb, servo-dev-board.kicad_sch, servo-test-board.kicad_sch]
2024-12-19 update servo-dev-board
    [servo-dev-board.kicad_pcb, servo-dev-board.kicad_sch]
2024-12-20 rework vias according updated constraints from jlc pcb
    [servo-dev-board.kicad_pcb]
2024-12-20 various work from before...
    [DSG0008A.stp, OPTO-SMD-4_ITR1204SR10A.step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]
2024-12-25 adding pid
2025-01-01 remove unused board
    [servo-test-board.kicad_pcb, servo-test-board.kicad_sch]
2025-01-01 Fixed error in PCB. Lowered isense resistor to 1.5k Ohm to increase max servo current to 1.5A
    [servo-dev-board.kicad_pcb, servo-dev-board.kicad_sch]
2025-01-01 added version, board, author info
    [servo-dev-board.kicad_pcb, servo-dev-board.kicad_sch]
2025-01-06 various experiments with firmware. Nothing is working yet
    [encoder-board.kicad_sch]
2025-01-27 add production and gerber files
    [servo-dev-board-CuBottom.gbr, servo-dev-board-CuIn1.gbr, servo-dev-board-CuIn2.gbr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]
2025-02-08 made pwm -> adc -> dma work
2025-02-12 ensure adc sample values are correct
    [main.rs]
2025-02-12 convert adc values
2025-02-16 made basic pid in firmware
